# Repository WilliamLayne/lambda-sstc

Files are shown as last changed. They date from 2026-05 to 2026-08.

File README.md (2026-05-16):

This project is based on Class-E Tesla Coil designs by Steve Ward and Labcoatz.   
https://stevehv.4hv.org/classEsstc.htm   
https://www.instructables.com/Making-the-Ultimate-Class-E-Musical-Tesla-Coil-Sin/ 

This project is a work in progress in collaboration with the Mines Maker Society for a kickoff workshop this coming fall semester. Expect build documentation sometime this May/June.

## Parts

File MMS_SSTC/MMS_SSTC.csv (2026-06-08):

Reference | Qty | Exclude from BOM | Exclude from Board | DKPN
SW1 | 30 |  | Excluded from board | R4ABLKBLKFF0-ND
C13 | 30 |  |  | P16846-ND
Y1 | 30 |  |  | MXO45HST-3C-1M000000
Q1 | 30 |  |  | FQA8N100CFS-ND
R4 | 30 |  |  | BC1.00KXCT-ND
R5 | 30 |  |  | A142822CT-ND
J1,J2 | 60 |  |  | 732-10956-ND
R2 | 30 |  |  | 56-MBA02040C6802FRP00CT-ND
R1 | 30 |  |  | 56-MBA02040C1802FRP00CT-ND
R3 | 30 |  |  | 56-MBA02040C1508FC100CT-ND
D2 | 30 |  |  | 5272-DB105-ND
U4 | 30 |  |  | 497-1452-5-ND
U5 | 30 |  |  | 497-1443-5-ND
C10 | 30 |  |  | 495-3207-ND
C12 | 30 |  |  | 493-12789-1-ND
C14 | 30 |  |  | 493-7077-ND
D3 | 30 |  |  | 4878-1N5408CT-ND
C9 | 30 |  |  | 399-R82DC3330SH60JCT-ND
C1,C2,C3,C4,C5,C6,C7,C8 | 250 |  |  | 399-4264-ND
TR1 | 30 |  |  | 3388-BV301S18028-ND
U1 | 30 |  |  | 296-NE555P-ND
U2 | 30 |  |  | 296-13689-5-ND
F1 | 30 |  |  | 283-4690-1-ND
D1 | 30 |  |  | 1N4148FSCT-ND
TVS1 | 30 |  |  | 13-SA15CA/BCT-ND

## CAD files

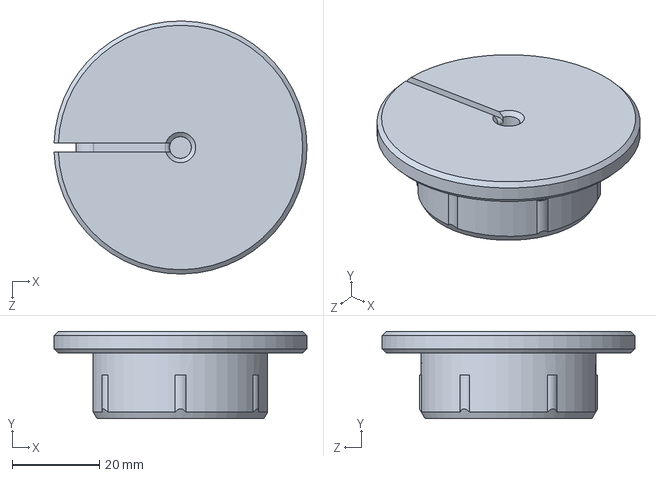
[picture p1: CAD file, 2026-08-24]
Case/Coil_Cap.SLDPRT
58.0 x 20.0 x 58.0 mm

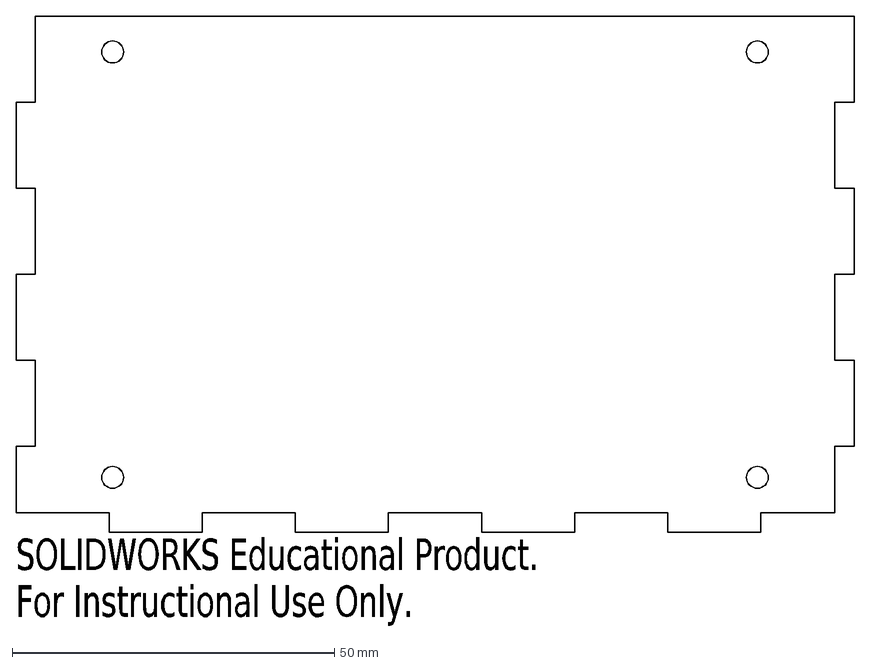
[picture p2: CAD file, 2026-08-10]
Case/production-files/drawings/Panel_Left.DXF
SOLIDWORKS Educational Product.
For Instructional Use Only.

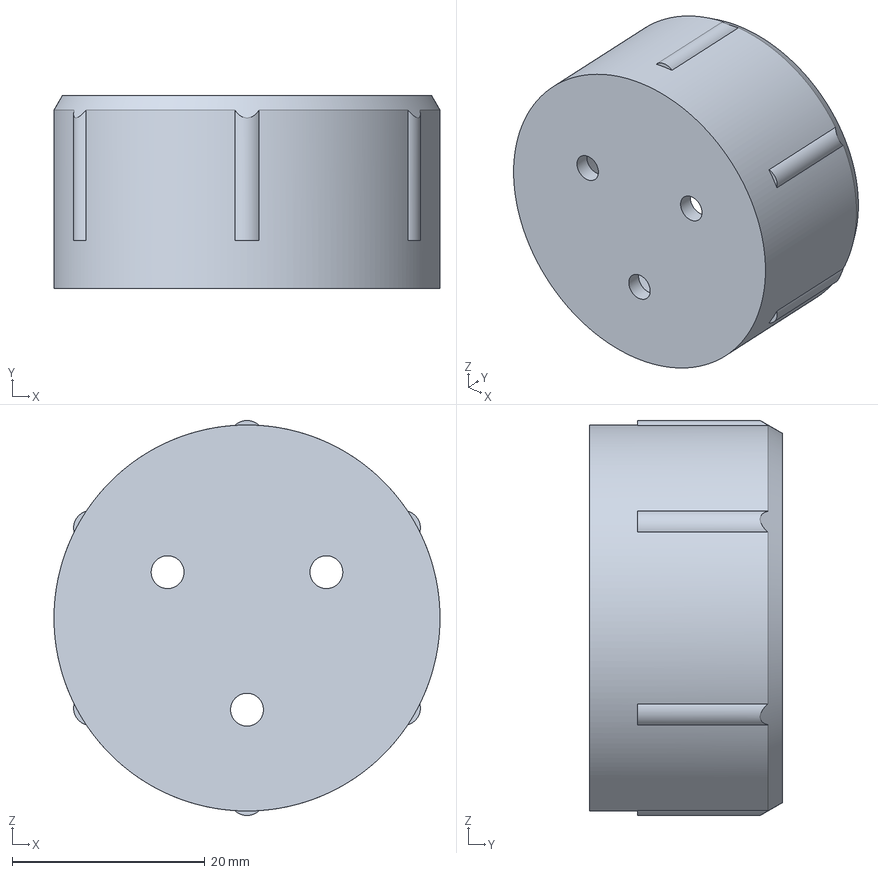
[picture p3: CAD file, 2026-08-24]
Case/production-files/meshes/Secondary_Holder.3MF
40.0 x 20.0 x 40.9 mm

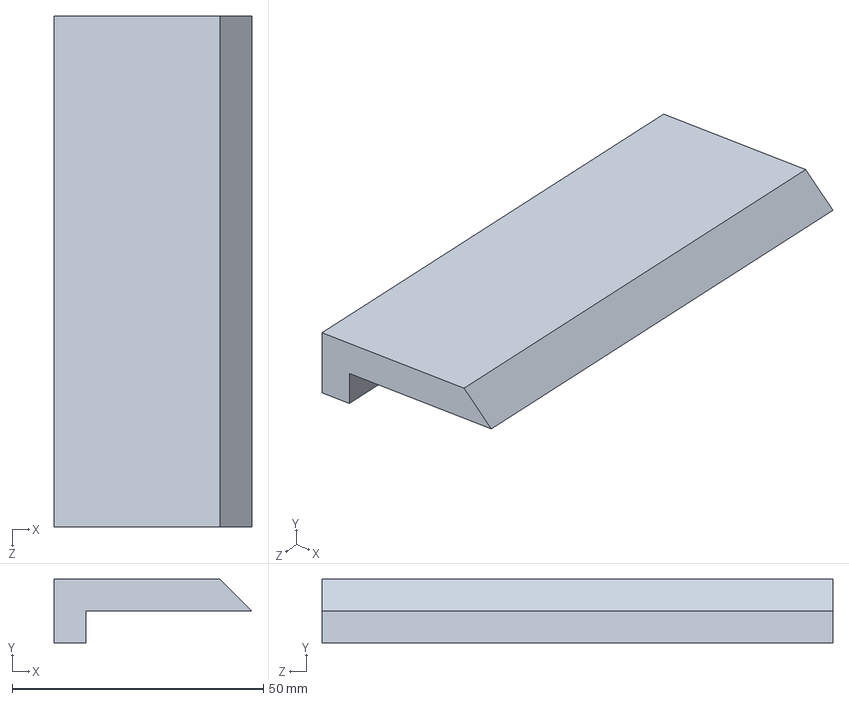
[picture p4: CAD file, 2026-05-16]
Jigs/heatsink-marking-template.SLDPRT
39.3 x 12.7 x 101.6 mm

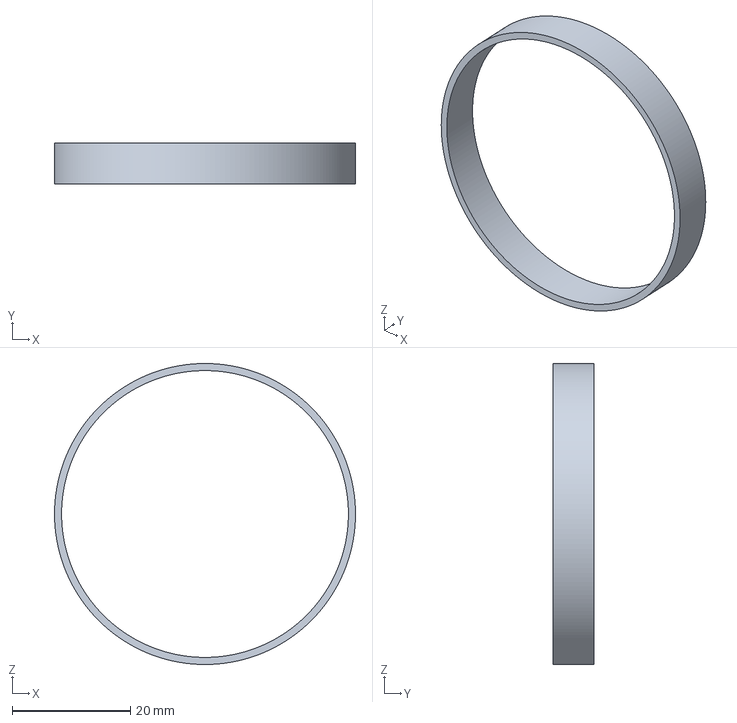
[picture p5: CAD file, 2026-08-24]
Jigs/production-files/Lower_Coil_Marking_Jig.3MF
50.8 x 7.00 x 50.8 mm

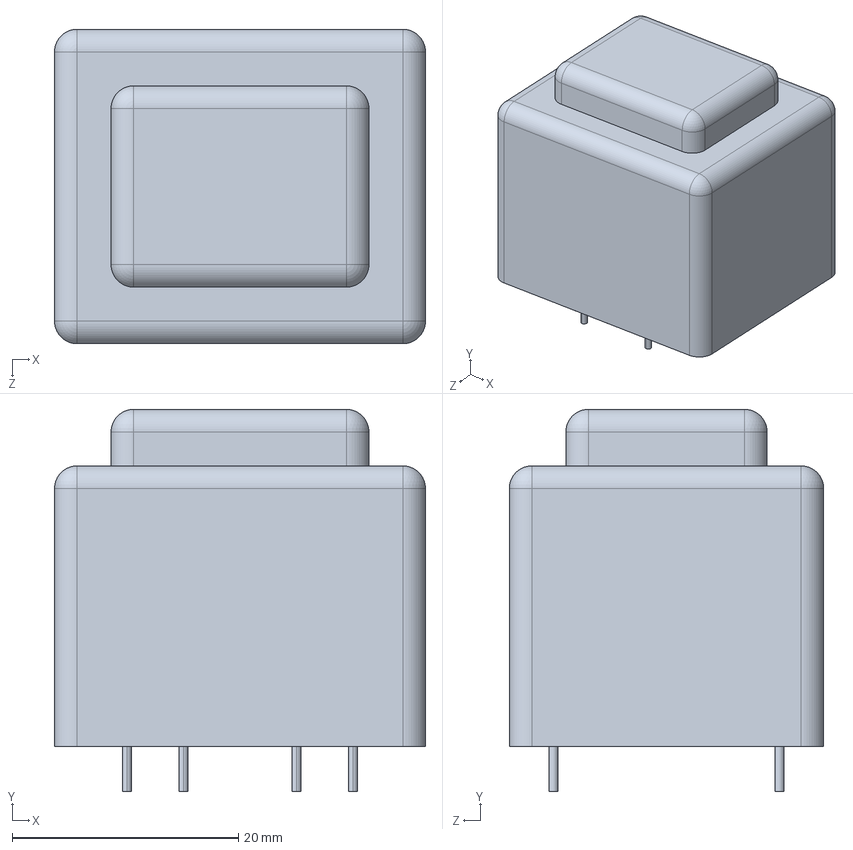
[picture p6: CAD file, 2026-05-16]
MMS_SSTC/local-models/transformer.STEP
32.8 x 33.8 x 27.8 mm

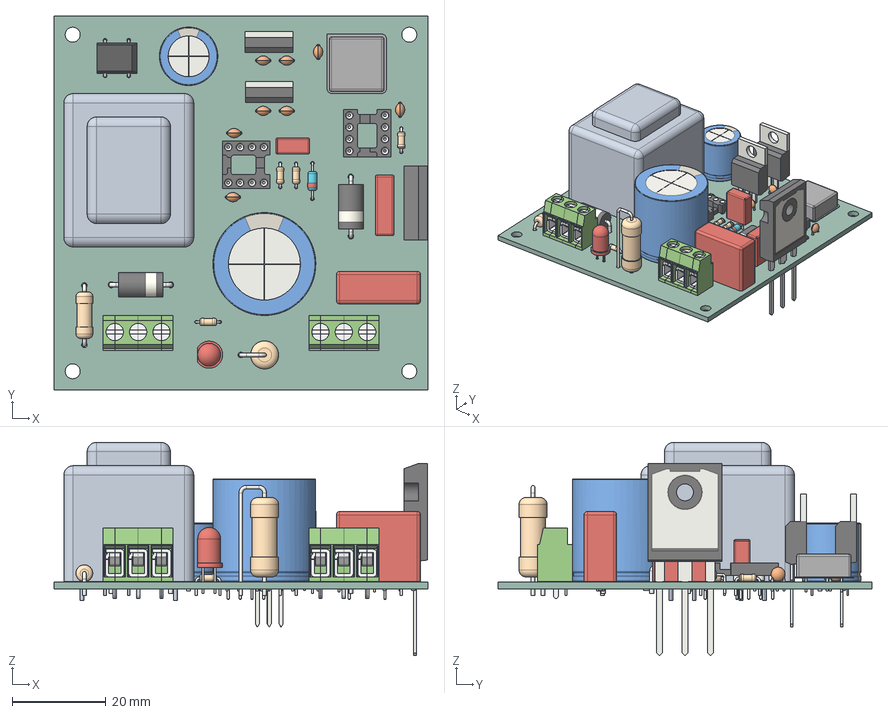
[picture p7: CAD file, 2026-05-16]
MMS_SSTC/PCB.step
80.0 x 80.0 x 45.6 mm
TO-247-3_Vertical
C_Disc_D3.0mm_W2.0mm_P2.50mm x 8
R_Axial_DIN0204_L3.6mm_D1.6mm_P5.08mm_Horizontal x 4
MRT12P5_SX x 2
MRT12P5_CNT x 4
MRT12P5_DX x 2
LED_D5.0mm
R_Axial_DIN0411_L9.9mm_D3.6mm_P12.70mm_Horizontal
transformer
DIP-8_W7.62mm_Socket x 2
TO-220-3_Vertical x 2
Diode_Bridge_DIP-4_W7.62mm_P5.08mm
D_DO-201_P12.70mm_Horizontal
C_Rect_L13.0mm_W4.0mm_P10.00mm_FKS3_FKP3_MKS4
D_DO-27_P12.70mm_Horizontal
R_Axial_DIN0617_L17.0mm_D6.0mm_P5.08mm_Vertical
CP_Radial_D12.5mm_P5.00mm
C_Rect_L18.0mm_W7.0mm_P15.00mm_FKS3_FKP3
CP_Radial_D22.0mm_P10.00mm_SnapIn
Oscillator_DIP-8
C_Rect_L7.2mm_W3.5mm_P5.00mm_FKS2_FKP2_MKS2_MKP2
D_DO-35_SOD27_P7.62mm_Horizontal
MMS_SSTC_PCB

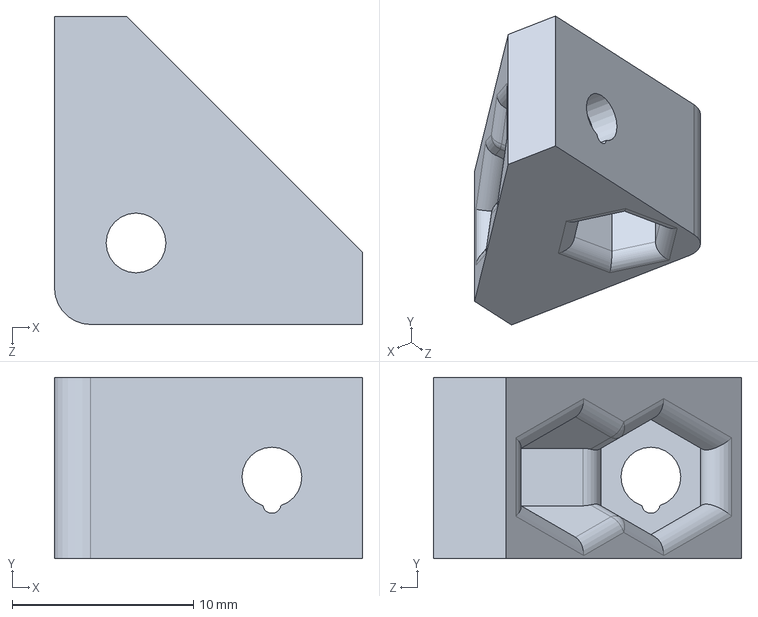
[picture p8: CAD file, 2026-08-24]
Case/Corner_Piece.SLDPRT
17.0 x 10.0 x 17.0 mm

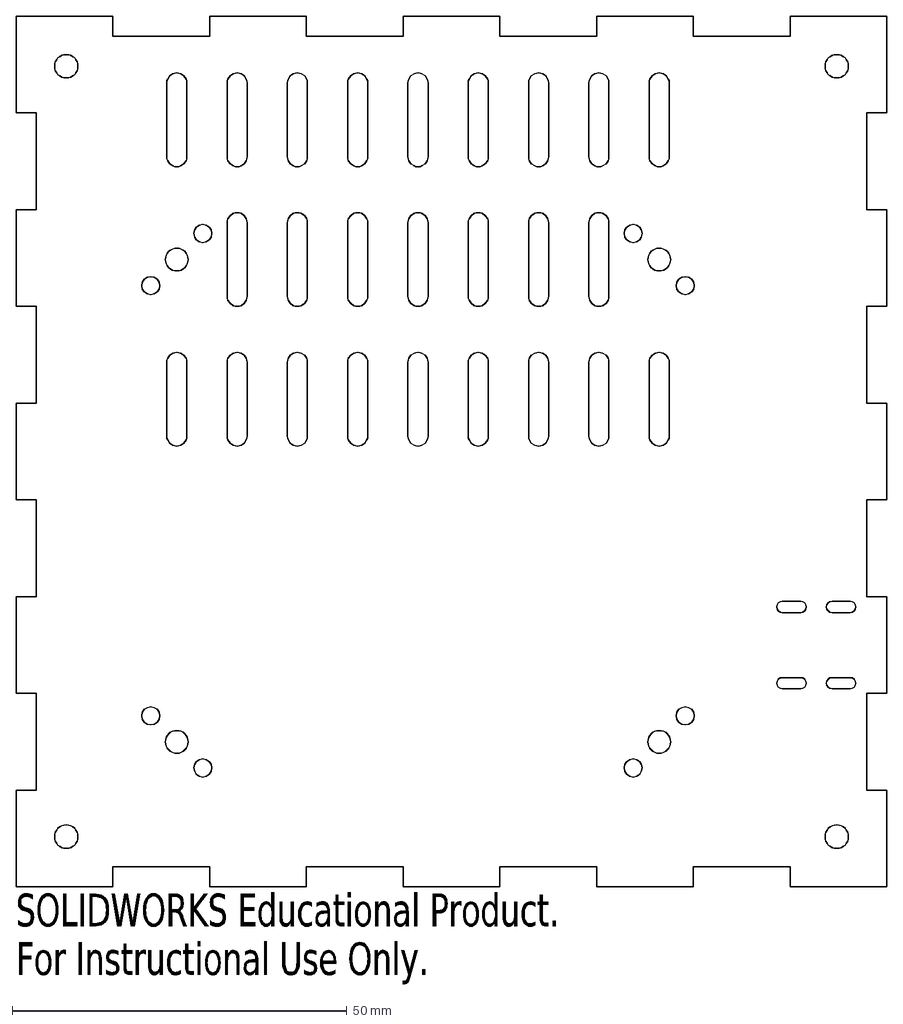
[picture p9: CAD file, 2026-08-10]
Case/production-files/drawings/Panel_Base.DXF
SOLIDWORKS Educational Product.
For Instructional Use Only.

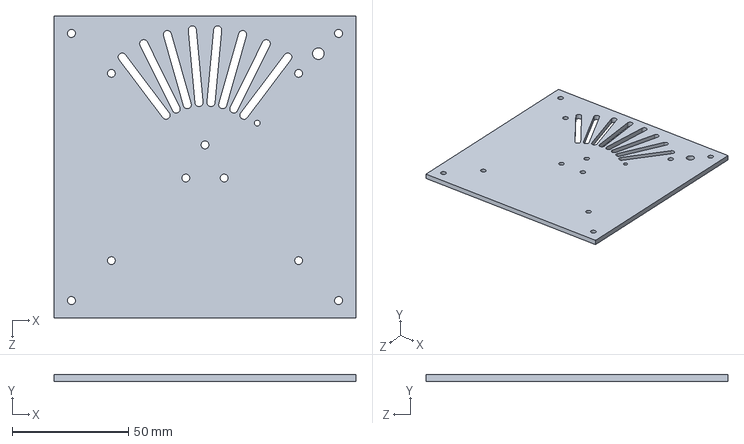
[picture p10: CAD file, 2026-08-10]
Case/Panel_Top.SLDPRT
130.0 x 3.00 x 130.0 mm

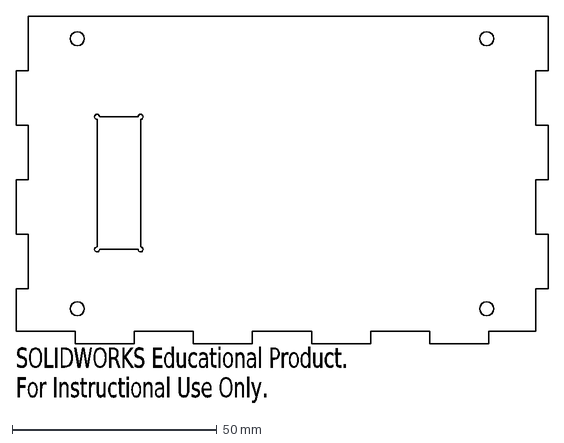
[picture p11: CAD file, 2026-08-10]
Case/production-files/drawings/Panel_Front.DXF
SOLIDWORKS Educational Product.
For Instructional Use Only.

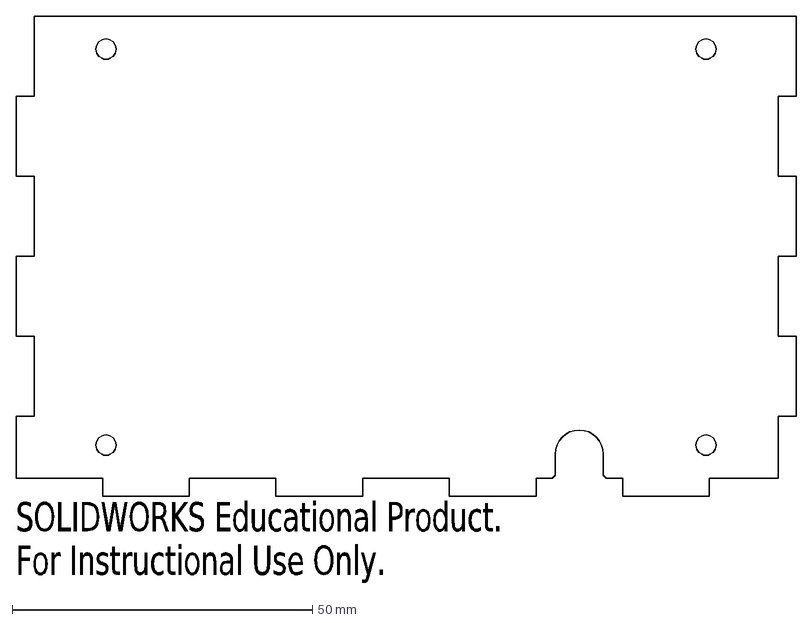
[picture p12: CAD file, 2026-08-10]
Case/production-files/drawings/Panel_Right.DXF
SOLIDWORKS Educational Product.
For Instructional Use Only.

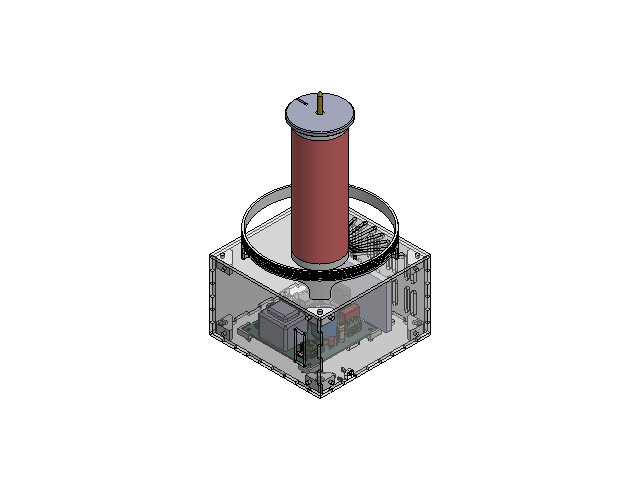
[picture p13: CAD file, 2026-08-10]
Case/Assembly.SLDASM
MRT12P5_SX_2.step x 2
MRT12P5_CNT_2.step x 4
MRT12P5_DX_2.step x 2
TO-247-3_Vertical_2.step
C_Disc_D3.0mm_W2.0mm_P2.50mm_2.step x 8
R_Axial_DIN0204_L3.6mm_D1.6mm_P5.08mm_Horizontal_2.step x 4
LED_D5.0mm_2.step
R_Axial_DIN0411_L9.9mm_D3.6mm_P12.70mm_Horizontal_2.step
transformer_2.step
DIP-8_W7.62mm_Socket_2.step x 2
TO-220-3_Vertical_2.step x 2
Diode_Bridge_DIP-4_W7.62mm_P5.08mm_2.step
D_DO-201_P12.70mm_Horizontal_2.step
C_Rect_L13.0mm_W4.0mm_P10.00mm_FKS3_FKP3_MKS4_2.step
D_DO-27_P12.70mm_Horizontal_2.step
R_Axial_DIN0617_L17.0mm_D6.0mm_P5.08mm_Vertical_2.step
CP_Radial_D12.5mm_P5.00mm_2.step
C_Rect_L18.0mm_W7.0mm_P15.00mm_FKS3_FKP3_2.step
CP_Radial_D22.0mm_P10.00mm_SnapIn_2.step
Oscillator_DIP-8_2.step
C_Rect_L7.2mm_W3.5mm_P5.00mm_FKS2_FKP2_MKS2_MKP2_2.step
D_DO-35_SOD27_P7.62mm_Horizontal_2.step
MMS_SSTC_PCB_2.step
Panel_Base
Panel_Top
Secondary_Holder
Primary_Form
Panel_Left
Panel_Right
PCB_Standoff x 4
Panel_Back
Panel_Front
Secondary_Form
Coil_Cap
Breakout_Point
Corner_Piece x 8
Heatsink
M3x10

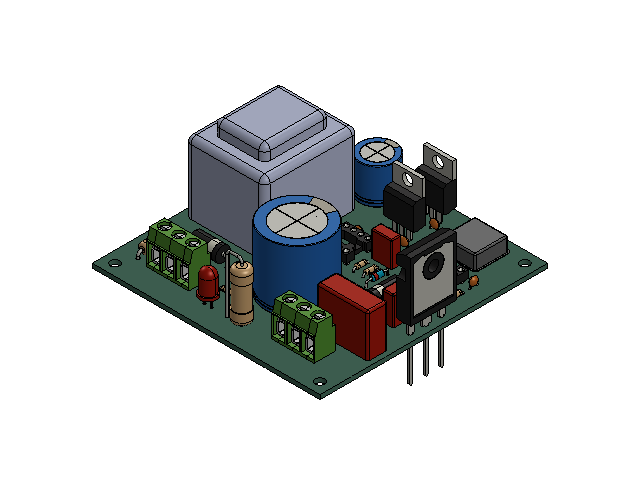
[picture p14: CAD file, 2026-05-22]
Case/PCB.SLDASM
MRT12P5_SX_2.step x 2
MRT12P5_CNT_2.step x 4
MRT12P5_DX_2.step x 2
TO-247-3_Vertical_2.step
C_Disc_D3.0mm_W2.0mm_P2.50mm_2.step x 8
R_Axial_DIN0204_L3.6mm_D1.6mm_P5.08mm_Horizontal_2.step x 4
LED_D5.0mm_2.step
R_Axial_DIN0411_L9.9mm_D3.6mm_P12.70mm_Horizontal_2.step
transformer_2.step
DIP-8_W7.62mm_Socket_2.step x 2
TO-220-3_Vertical_2.step x 2
Diode_Bridge_DIP-4_W7.62mm_P5.08mm_2.step
D_DO-201_P12.70mm_Horizontal_2.step
C_Rect_L13.0mm_W4.0mm_P10.00mm_FKS3_FKP3_MKS4_2.step
D_DO-27_P12.70mm_Horizontal_2.step
R_Axial_DIN0617_L17.0mm_D6.0mm_P5.08mm_Vertical_2.step
CP_Radial_D12.5mm_P5.00mm_2.step
C_Rect_L18.0mm_W7.0mm_P15.00mm_FKS3_FKP3_2.step
CP_Radial_D22.0mm_P10.00mm_SnapIn_2.step
Oscillator_DIP-8_2.step
C_Rect_L7.2mm_W3.5mm_P5.00mm_FKS2_FKP2_MKS2_MKP2_2.step
D_DO-35_SOD27_P7.62mm_Horizontal_2.step
MMS_SSTC_PCB_2.step

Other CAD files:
Case/production-files/meshes/Coil_Cap.3MF
Jigs/Lower_Coil_Marking_Jig.SLDPRT
Case/production-files/meshes/Corner_Piece.3MF
Case/Panel_Base.SLDPRT
Case/Breakout_Point.SLDPRT
Case/Heatsink.SLDPRT
Case/M3n.SLDPRT
Case/M3x10.SLDPRT
Case/M3x18.SLDPRT
Case/PCB_Standoff.SLDPRT
Case/Panel_Back.SLDPRT
Case/Panel_Front.SLDPRT
Case/Panel_Left.SLDPRT
Case/Panel_Right.SLDPRT
Case/Primary_Form.SLDPRT
Case/Secondary_Form.SLDPRT
Case/Secondary_Holder.SLDPRT
Case/Switch_Test.SLDPRT
Case/production-files/drawings/Panel_Back.DXF
Case/production-files/drawings/Panel_Top.DXF
Case/production-files/meshes/PCB_Standoff.3MF
Case/production-files/meshes/Primary_Form.3MF
MMS_SSTC/local-models/691137710002.step
MMS_SSTC/local-models/691137710003.step

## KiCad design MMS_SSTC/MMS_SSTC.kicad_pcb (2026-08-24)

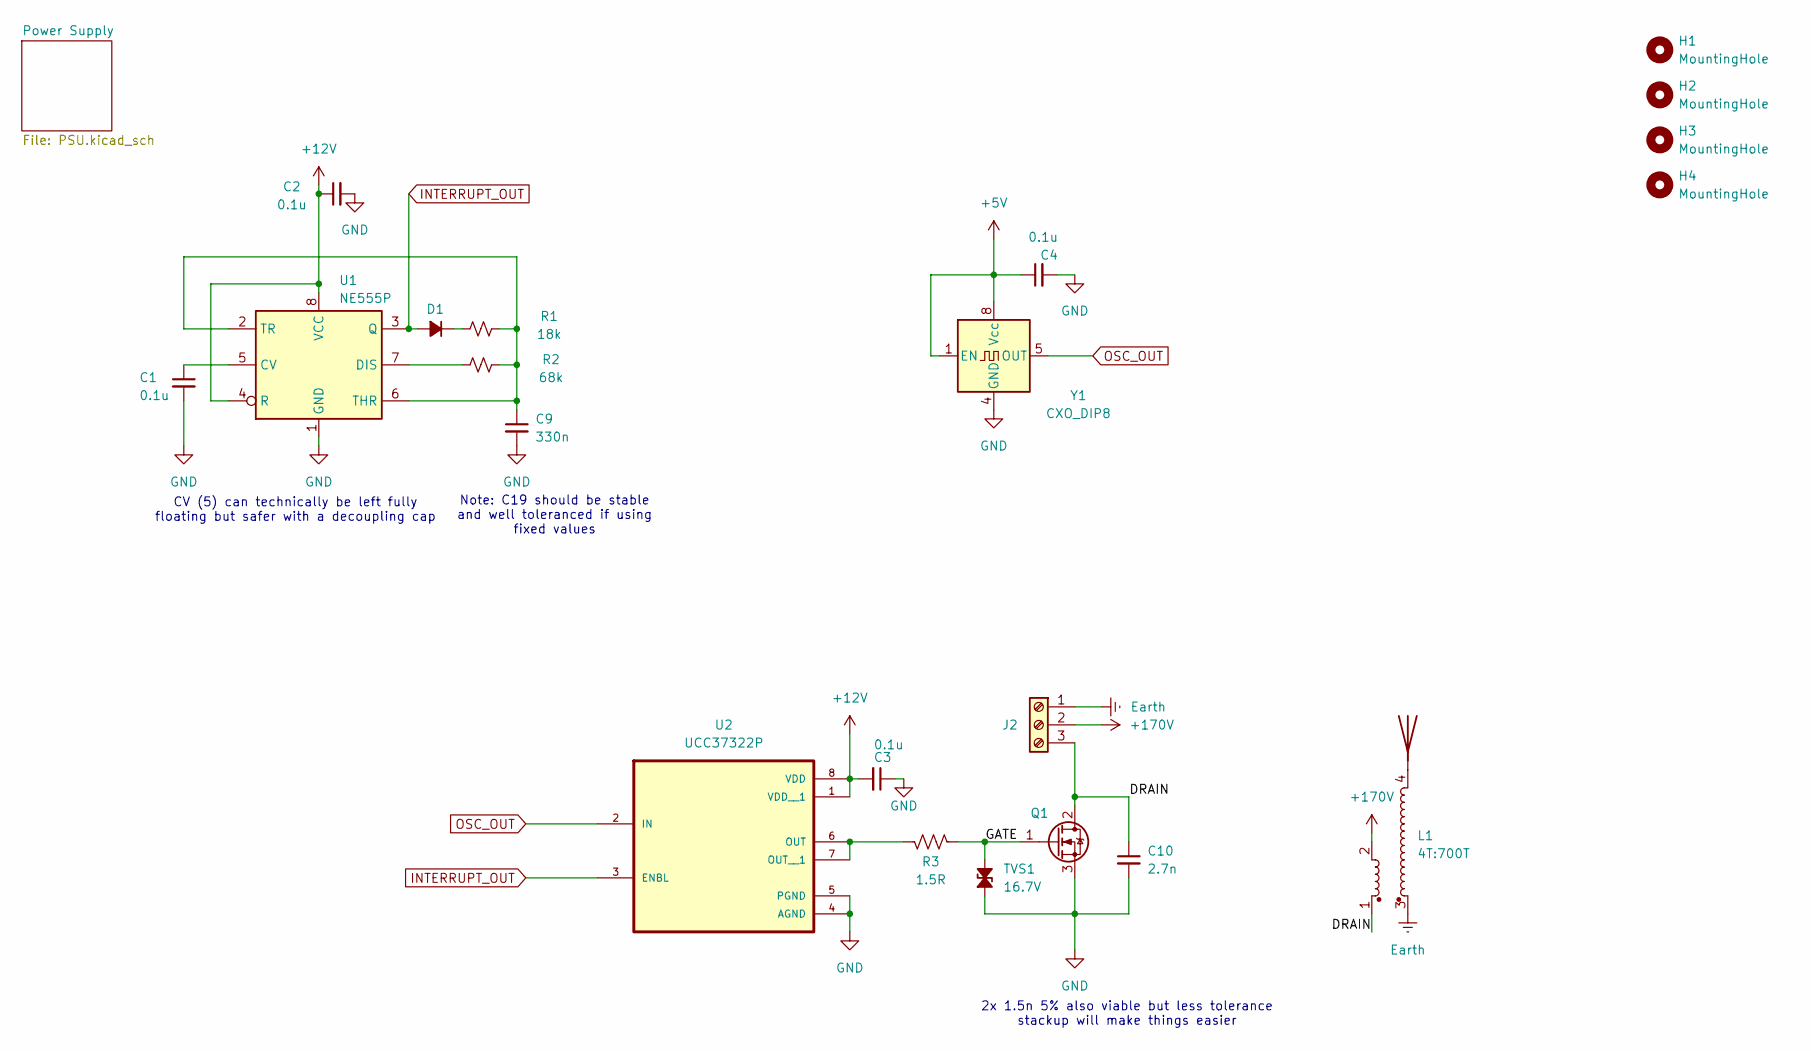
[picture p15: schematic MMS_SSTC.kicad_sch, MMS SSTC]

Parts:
AE1: Antenna
C1, C2, C3, C4: 0.1u; C_Disc_D3.0mm_W2.0mm_P2.50mm
C9: 330n; C_Rect_L7.2mm_W3.5mm_P5.00mm_FKS2_FKP2_MKS2_MKP2
C10: 2.7n; C_Rect_L13.0mm_W4.0mm_P10.00mm_FKS3_FKP3_MKS4
D1: D_Small_Filled; D_DO-35_SOD27_P7.62mm_Horizontal
H1, H2, H3, H4: MountingHole; MountingHole_3.2mm_M3
J2: Screw_Terminal_01x02; 691137710003
L1: 4T:700T
Q1: FQA8N100C; TO-247-3_Vertical
R1: 18k; R_Axial_DIN0204_L3.6mm_D1.6mm_P5.08mm_Horizontal
R2: 68k; R_Axial_DIN0204_L3.6mm_D1.6mm_P5.08mm_Horizontal
R3: 1.5R; R_Axial_DIN0204_L3.6mm_D1.6mm_P5.08mm_Horizontal
TVS1: 16.7V; D_DO-15_P10.16mm_Horizontal
U1: NE555P; DIP-8_W7.62mm_Socket
U2: UCC37322P; DIP-8_W7.62mm_Socket
Y1: CXO_DIP8; Oscillator_DIP-8

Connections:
+5V: C4.1, Y1.1 (EN), Y1.8 (Vcc); also elsewhere on the board
+12V: C2.1, C3.2, U1.4 (R), U1.8 (VCC), U2.1 (VDD__1), U2.8 (VDD); also elsewhere on the board
+170V: J2.2, L1.2; also elsewhere on the board
/DRAIN: C10.1, J2.3, L1.1, Q1.2 (D)
/GATE: Q1.1 (G), R3.1, TVS1.2 (A2)
Earth: J2.1, L1.3; also elsewhere on the board
GND: C1.2, C2.2, C3.1, C4.2, C9.2, C10.2, Q1.3 (S), TVS1.1 (A1), U1.1 (GND), U2.4 (AGND), U2.5 (PGND), Y1.4 (GND); also elsewhere on the board
INTERRUPT_OUT: D1.2 (A), U1.3 (Q), U2.3 (ENBL)
unnamed: AE1.1, L1.4
unnamed: D1.1 (K), R1.1
unnamed: C1.1, U1.5 (CV)
unnamed: R2.1, U1.7 (DIS)
unnamed: C9.1, R1.2, R2.2, U1.2 (TR), U1.6 (THR)
unnamed: R3.2, U2.6 (OUT), U2.7 (OUT__1)
OSC_OUT: U2.2 (IN), Y1.5 (OUT)

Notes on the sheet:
2x 1.5n 5% also viable but less tolerance stackup will make things easier
Note: C19 should be stable and well toleranced if using fixed values
CV (5) can technically be left fully floating but safer with a decoupling cap

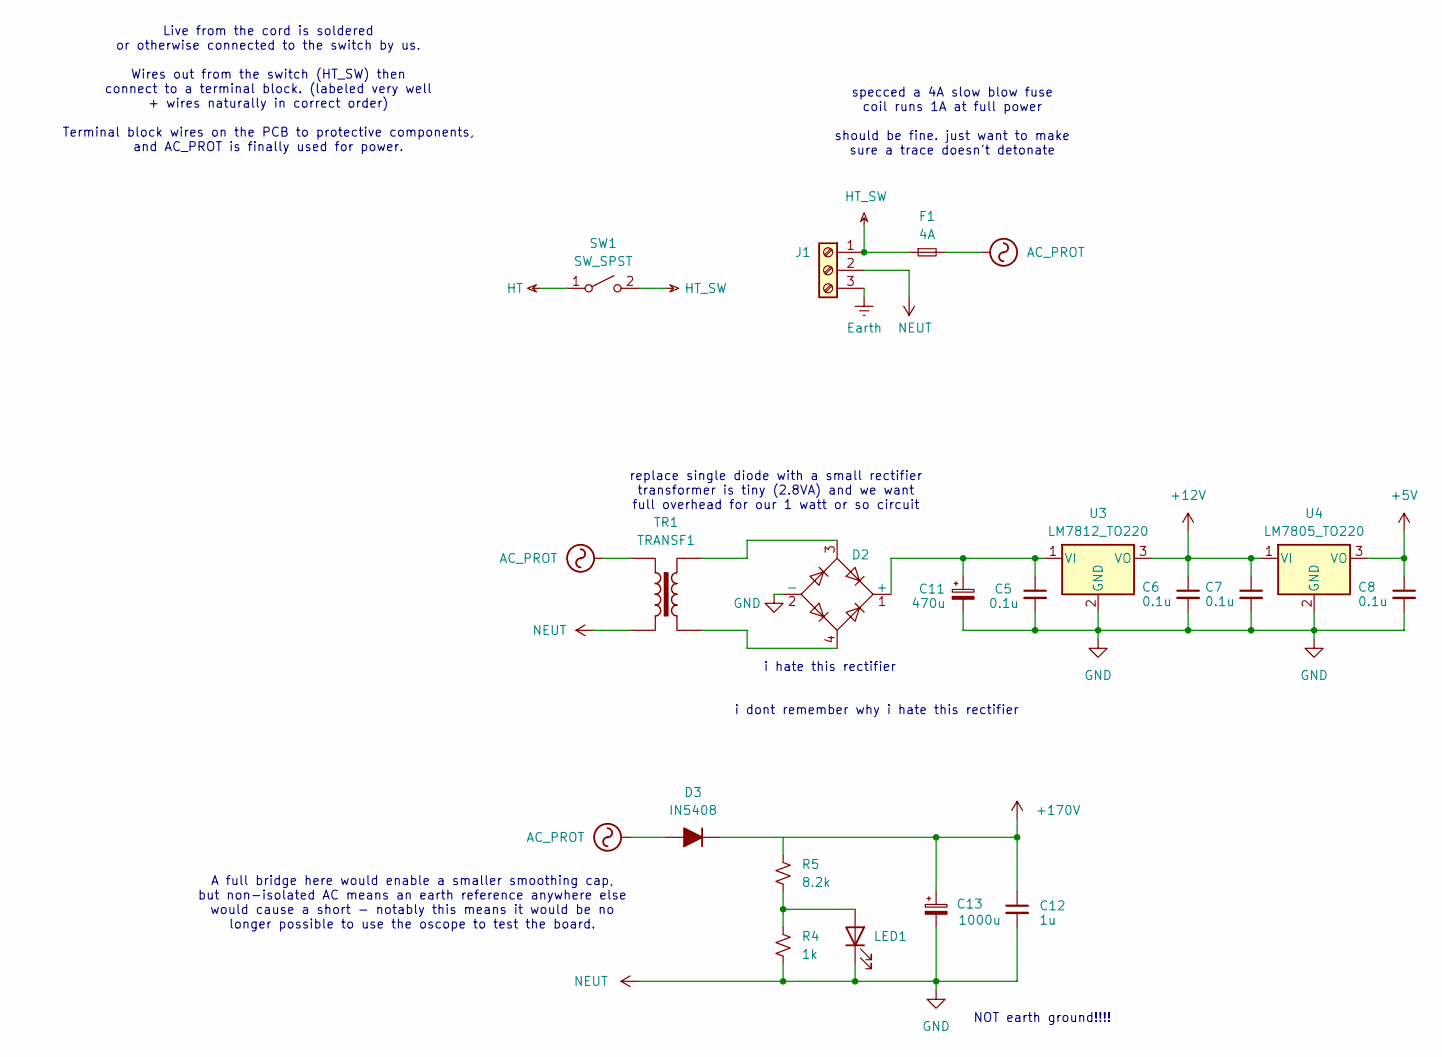
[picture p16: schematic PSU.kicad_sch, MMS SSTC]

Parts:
C5, C6, C7, C8: 0.1u; C_Disc_D3.0mm_W2.0mm_P2.50mm
C11: 470u; CP_Radial_D12.5mm_P5.00mm
C12: 1u; C_Rect_L18.0mm_W7.0mm_P15.00mm_FKS3_FKP3
C13: 1000u; CP_Radial_D22.0mm_P10.00mm_SnapIn
D2: DB105; Diode_Bridge_DIP-4_W7.62mm_P5.08mm
D3: IN5408; D_DO-201_P12.70mm_Horizontal
F1: 4A; R_Axial_DIN0411_L9.9mm_D3.6mm_P12.70mm_Horizontal
J1: Screw_Terminal_01x02; 691137710003
LED1: LED; LED_D5.0mm
R4: 1k; R_Axial_DIN0204_L3.6mm_D1.6mm_P5.08mm_Horizontal
R5: 8.2k; R_Axial_DIN0617_L17.0mm_D6.0mm_P5.08mm_Vertical
SW1: SW_SPST
TR1: TRANSF1; Transformer_Zettler_BV301S18028
U3: LM7812_TO220; TO-220-3_Vertical
U4: LM7805_TO220; TO-220-3_Vertical

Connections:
+5V: C8.1, U4.3 (VO); also elsewhere on the board
+12V: C6.1, C7.1, U3.3 (VO), U4.1 (VI); also elsewhere on the board
+170V: C12.1, C13.1, D3.1 (K); also elsewhere on the board
AC_PROT: D3.2 (A), F1.2, TR1.1
Earth: J1.3; also elsewhere on the board
GND: C5.2, C6.2, C7.2, C8.2, C11.2, C12.2, C13.2, D2.2 (-), J1.2, LED1.1 (K), R4.2, TR1.2, U3.2 (GND), U4.2 (GND); also elsewhere on the board
HT_SW: F1.1, J1.1, SW1.2 (B)
unnamed: C5.1, C11.1, D2.1 (+), U3.1 (VI)
unnamed: D2.3, TR1.4
unnamed: D2.4, TR1.3
unnamed: LED1.2 (A), R4.1, R5.2

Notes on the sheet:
NOT earth ground!!!!
i hate this rectifier
i dont remember why i hate this rectifier
Live from the cord is soldered or otherwise connected to the switch by us. Wires out from the switch (HT_SW) then connect to a terminal block. (labeled very well + wires naturally in correct order) Terminal block wires on the PCB to protective components, and AC_PROT is finally used for power.
replace single diode with a small rectifier transformer is tiny (2.8VA) and we want full overhead for our 1 watt or so circuit
specced a 4A slow blow fuse coil runs 1A at full power should be fine. just want to make sure a trace doesn't detonate
A full bridge here would enable a smaller smoothing cap, but non-isolated AC means an earth reference anywhere else would cause a short - notably this means it would be no longer possible to use the oscope to test the board.

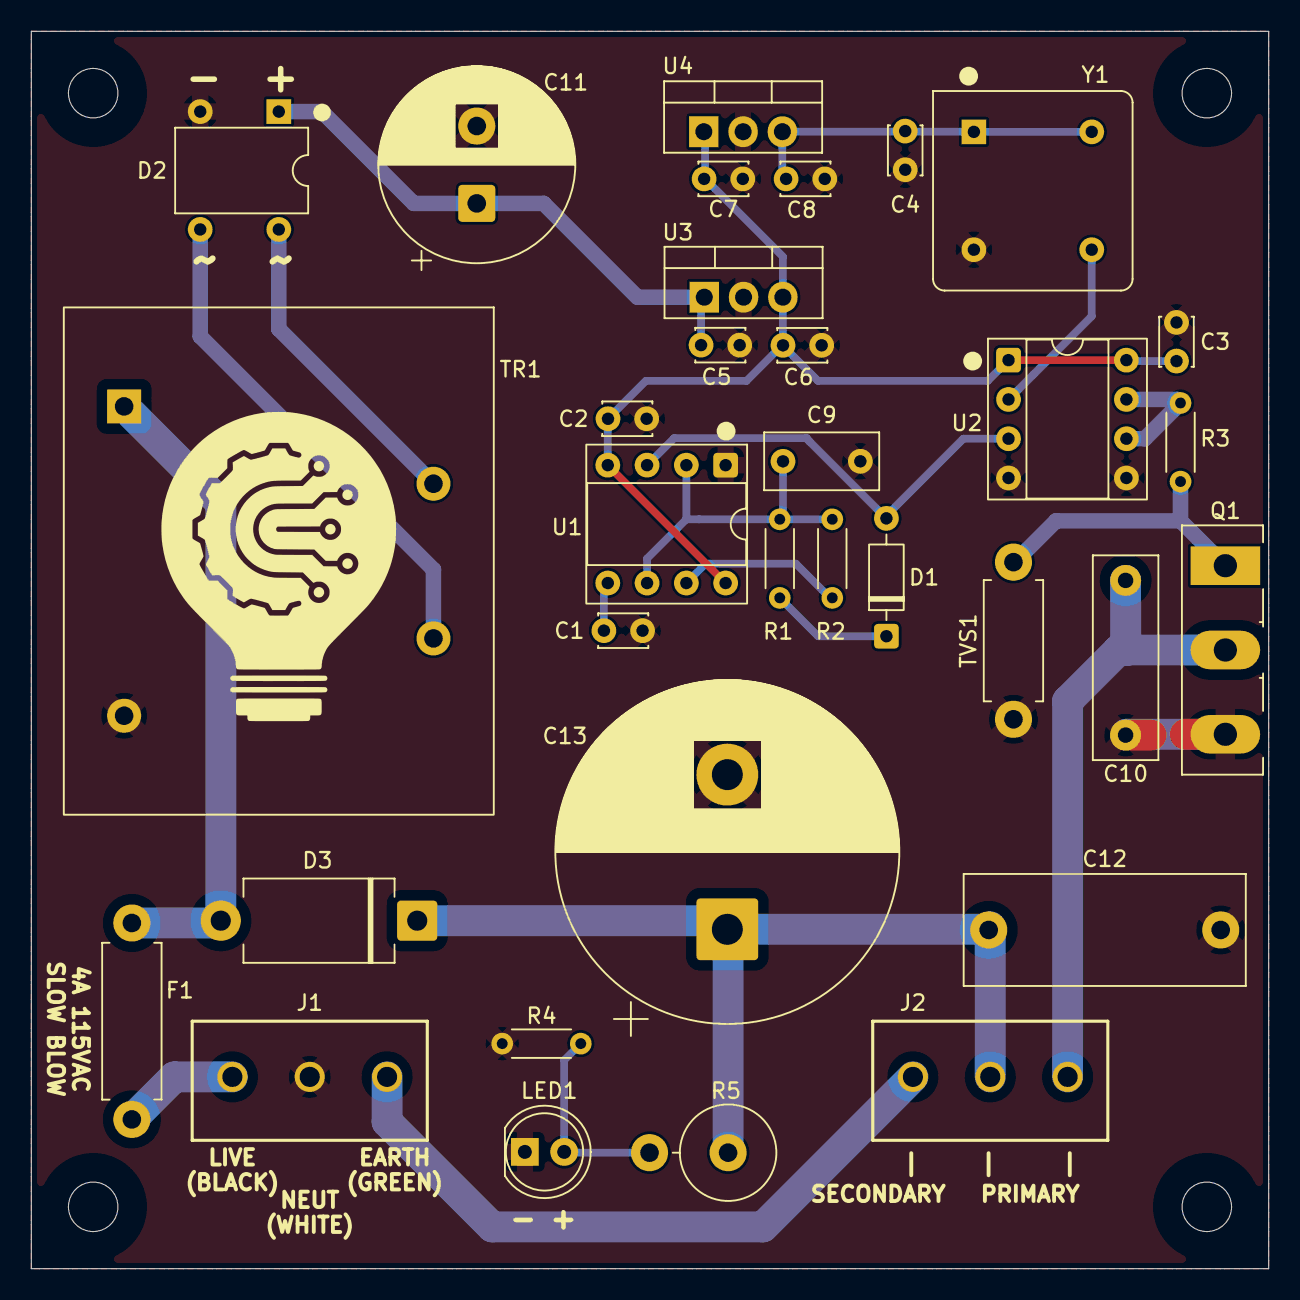
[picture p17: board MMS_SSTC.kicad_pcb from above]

Board: 2 copper layers, 80.0 x 80.0 mm, 37 parts (0 on the bottom side), 20 nets.

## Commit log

2026-05-16 Add new WIP and Mk. 1 files from FA25 workshop. KiCad and circuit design is finalized/finalized+tweaks for pre-production test. CAD files are still outdated to Mk. 1 version.
    [691137710002.step, 691137710003.step, Assembly.SLDASM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]
2026-05-16 Update PCB trace clearances
    [MMS_SSTC-B_Cu.gbl, MMS_SSTC-B_Mask.gbs, MMS_SSTC-B_Paste.gbp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]
2026-05-16 Get CAD semi-finished, tweak PCB
    [Assembly.SLDASM, Corner_Piece.SLDPRT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]
2026-05-22 Update heat sink and add zone clearance near screw holes
    [Assembly.SLDASM, Heatsink.SLDPRT, MMS_SSTC.kicad_pcb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]
2026-06-07 Update CAD and drawings for CPP quote, switch to 3mm acrylic
    [Assembly.SLDASM, M3x10.SLDPRT, Panel_Back.SLDPRT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]
2026-06-08 Update plots for final JLC order
    [Corner_Piece.3MF, M3x18.SLDPRT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]
2026-06-09 Clean up PCB after build test, add heat sink to assembly
    [Assembly.SLDASM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]
2026-08-10 Prepare drawing files for test cuts
    [Assembly.SLDASM, Panel_Back.DXF, Panel_Back.SLDPRT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]
2026-08-24 Prepare meshes for production
    [Coil_Cap.3MF, Coil_Cap.SLDPRT, Corner_Piece.3MF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]
